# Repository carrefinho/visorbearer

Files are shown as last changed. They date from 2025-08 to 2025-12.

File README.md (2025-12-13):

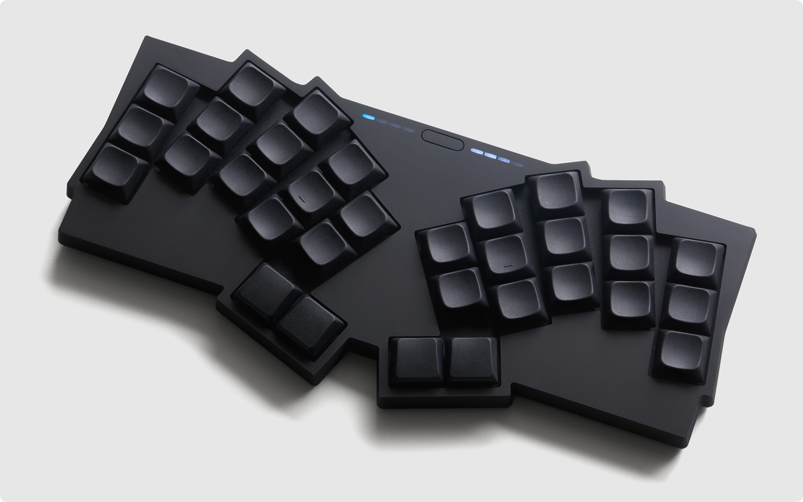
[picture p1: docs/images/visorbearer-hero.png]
Visorbearer keyboard


# Visorbearer

Visorbearer is a 32-key unibody split wireless keyboard featuring 8 RGB LED indicators.

Named after [hummingbirds in the genus Augastes](https://en.wikipedia.org/wiki/Visorbearer) for the Hummingbird layout connection and distinctive white bands on their chests that resemble the LED indicators.

> [!WARNING]
> This is a work in progress.

## To-Do

- [ ] Build Guide & BOM
- [ ] Case Printing Guide
- [ ] Alternative layout case files and guide
- [x] Revision 2 PCB testing + power profiling
- [x] Firmware Notes
- [ ] Design write-up
- [ ] More photos

## Design

https://github.com/user-attachments/assets/812049e3-29ce-48d4-8fe3-20bf21285e64

- 2x 4-segment RGB LED indicators
   - Discreet dead-front design: completely invisible when off
   - Connection bar: Bluetooth profiles and modifier keys
   - Battery bar: percentage and charging status
   - Powered by two TI LP5012 drivers with automatic low-power mode
- 32-key Hummingbird-ish layout with splay and inverted thumb cluster
   - Down to 26-key with case and plate variants
      - 2U thumb key support
- Hot-swap Kailh Choc v1 switches in Choc (18x17mm) spacing
   - <details> <summary>Limited Choc v2 compatibility</summary>

      The PCB is incompatible with older Choc v2 switches that have a third stabilizing pin. Newer Choc v2 releases without this pin work fine, such as: Lofree POM Phantom/Ghost/Specter/Hades and Kailh Hide Mountain/White Rain/Deep Sea Mini Islet/Deep Sea Mini Whale.

      Note that, for Choc v2, there are very few off-the-shelf options for choc-spaced keycaps with MX stems: as of late 2025, the only two are [Taihao THCS](https://shop.tai-hao.com/categories/thcs-low-profile-keycaps) and [Asymplex MX-stem Chicago Steno](https://www.asymplex.xyz/product/made-to-order-mx-stem-cs-kits). You could also 3D-print your own keycaps.

   </details>
- Seeed Studio XIAO nRF52840 **Plus** controller on ZMK firmware
- 3D-printed case and switch plate with switch puller grooves
   - Easily accessible reset button

<picture>
  <source media="(prefers-color-scheme: dark)" srcset="./docs/images/visorbearer-dimensions-dark.png">
  <source media="(prefers-color-scheme: light)" srcset="./docs/images/visorbearer-dimensions-light.png">
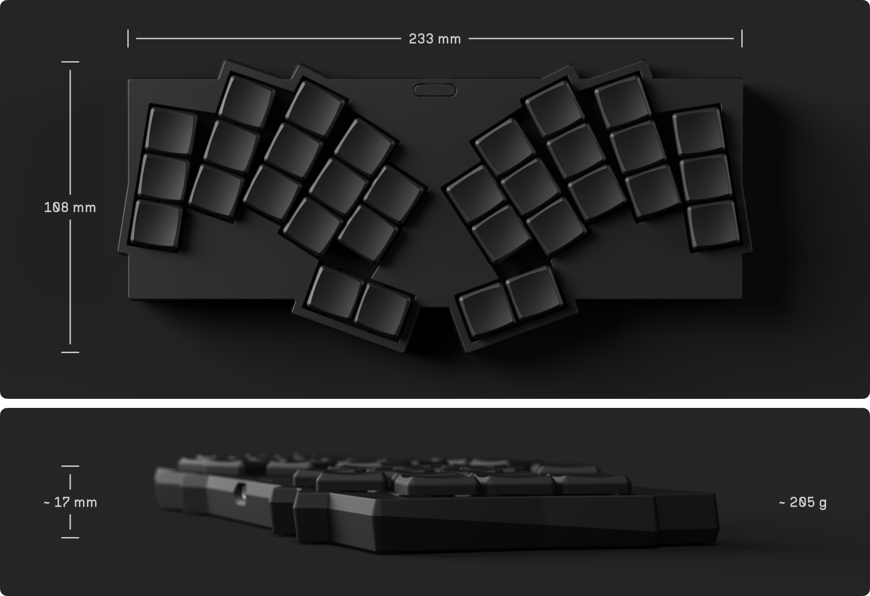
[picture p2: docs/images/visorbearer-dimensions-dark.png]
Visorbearer keyboard dimensions
  
</picture>

## Build Guide

> [!NOTE]
> Revision 2 PCB is tested and working. Build guide is work in progress.

[View the PCB on KiCanvas.](https://kicanvas.org/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)

[Find the build guide here.](/docs/build-guide.md)

## Firmware

[Find the ZMK module here.](https://github.com/carrefinho/visorbearer-zmk-module)

## Gallery

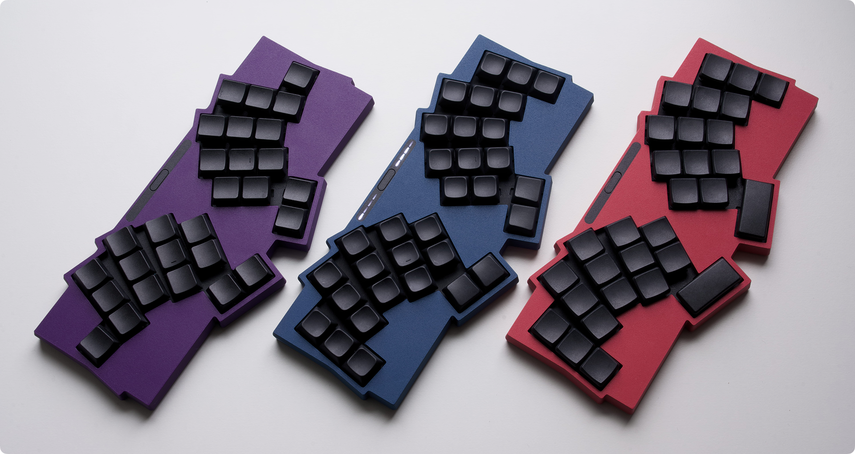
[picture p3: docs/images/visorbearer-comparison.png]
Comparison of Visorbearer keyboard in single pinkie, standard 32-key, and 2x 2U thumb layouts


## Inspirations & Acknowledgments

- Aesthetics
   - [GEIGEIGEIST/TOTEM](https://github.com/GEIGEIGEIST/TOTEM)
   - [weteor/Grumpy](https://github.com/weteor/Grumpy)
   - [dohn-joh/alias](https://github.com/dohn-joh/alias)
- Layout
   - [bennytrouser/NostrumX](https://github.com/bennytrouser/NostrumX)
   - [davidphilipbarr/hypergolic](https://github.com/davidphilipbarr/hypergolic)
   - [davidphilipbarr/paroxysm](https://github.com/davidphilipbarr/paroxysm)
   - [grassfedreeve/akohekohe](https://github.com/grassfedreeve/akohekohe)
   - [hazels-garage/bad-wings](https://github.com/hazels-garage/bad-wings/tree/master/v2)
   - [kilipan/zilpzalp](https://github.com/kilipan/zilpzalp)
   - [weteor/Fitis](https://github.com/weteor/Fitis)
   - [weteor/Tipper-TF](https://github.com/weteor/Tipper-TF)
- LED indicator
   - [GEIGEIGEIST/KLOTZ](https://github.com/GEIGEIGEIST/KLOTZ)
   - [caksoylar/zmk-rgbled-widget](https://github.com/caksoylar/zmk-rgbled-widget): LED code
- Case
   - [duckyb/urchin](https://github.com/duckyb/urchin): Snap fit design
- And the lovely folks on the Fingerpunch discord who were along for the ride!

## License

Visorbearer is licensed under CERN-OHL-P-2.0.

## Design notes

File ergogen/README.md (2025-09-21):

Ergogen was only used to generate key positions, rest of the design including PCB outline and component placement was done with pcb_ref.dxf in Fusion and KiCad.

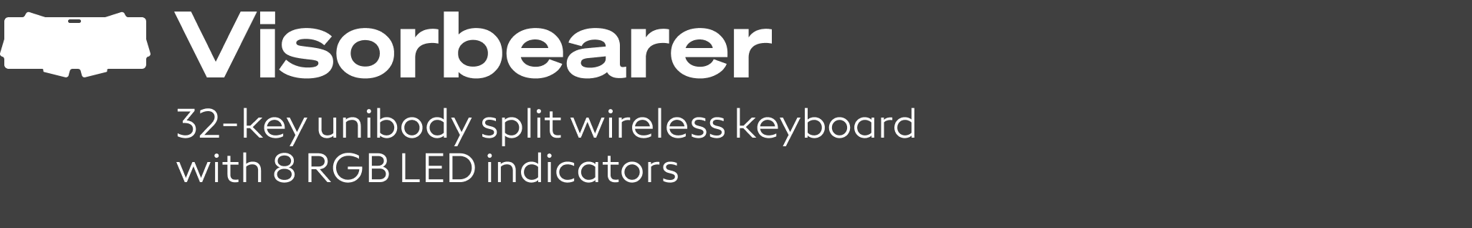
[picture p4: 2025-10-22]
docs/images/visorbearer-heading-dark.png

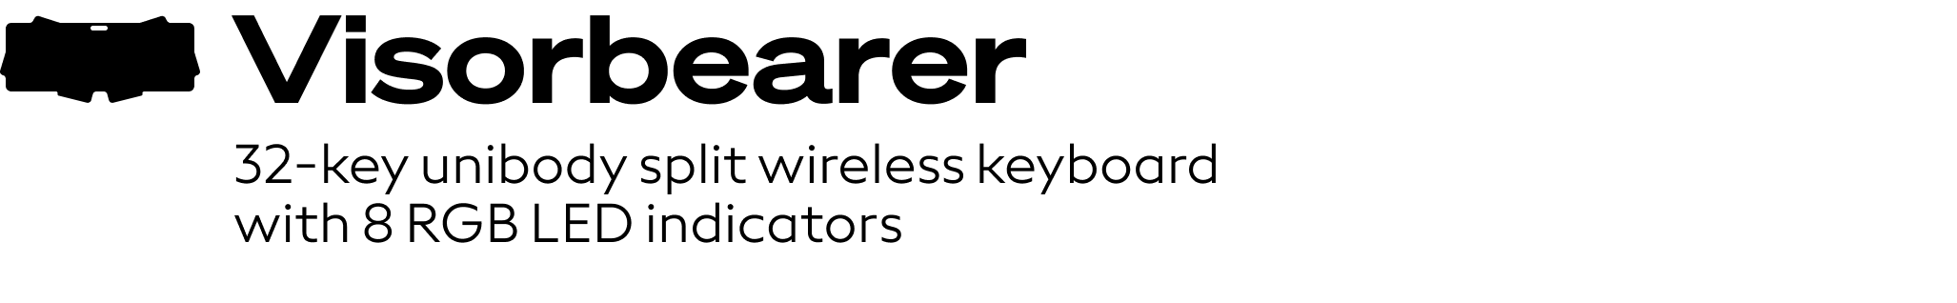
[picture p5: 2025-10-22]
docs/images/visorbearer-heading-light.png

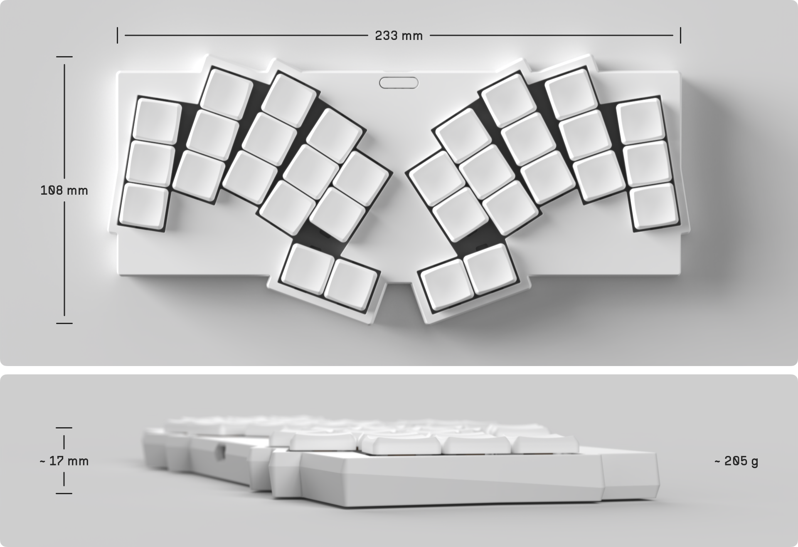
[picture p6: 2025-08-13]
docs/images/visorbearer-dimensions-light.png

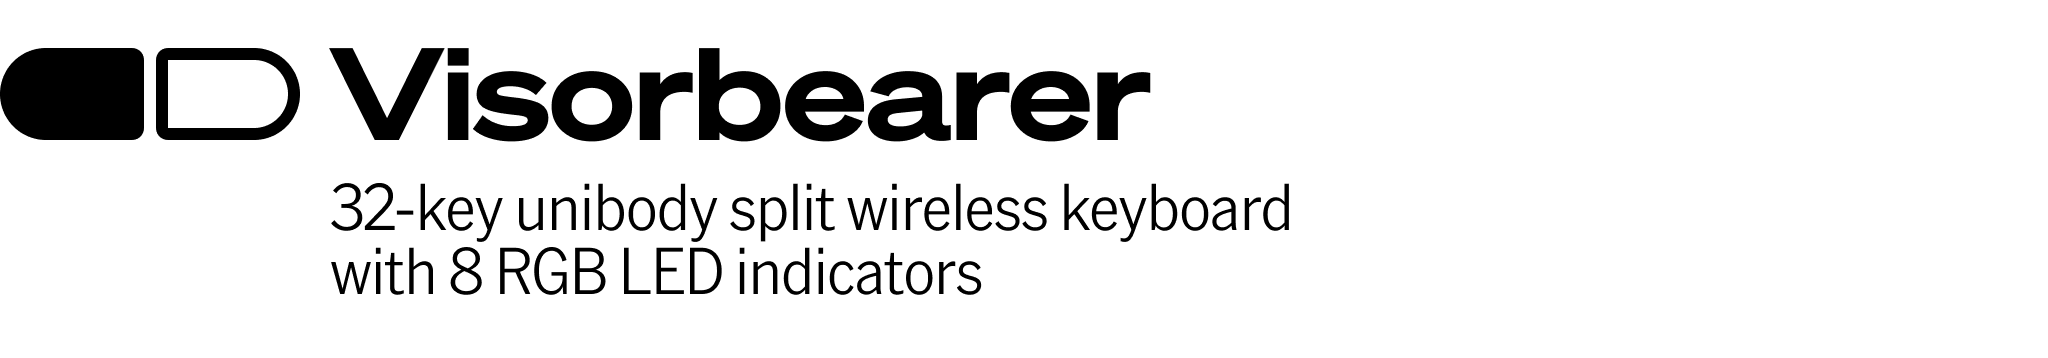
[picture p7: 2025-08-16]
docs/images/visorbearer-heading-dark-1.png

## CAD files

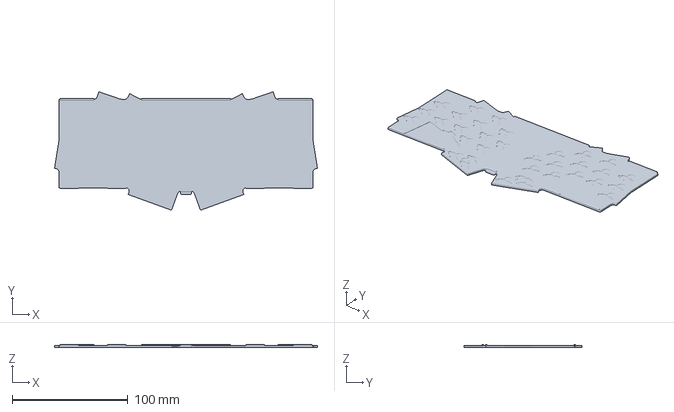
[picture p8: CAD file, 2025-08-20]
case/bottom-cover/visorbearer_bottom_cover_standard.3mf
227.2 x 102.4 x 3.00 mm

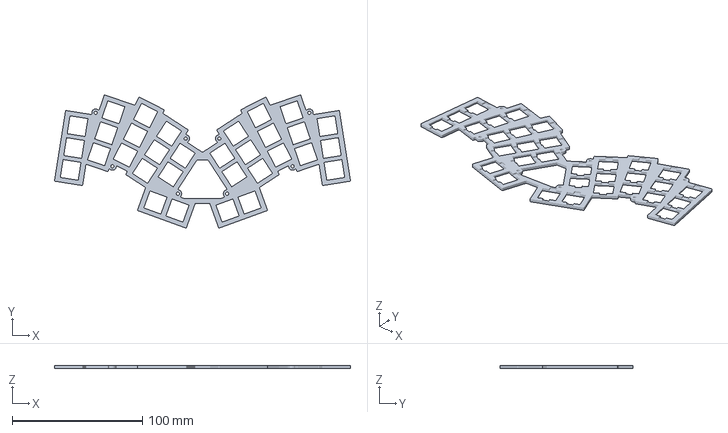
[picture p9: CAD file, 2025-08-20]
case/switch-plate/visorbearer_plate_standard.3mf
227.1 x 102.1 x 2.20 mm

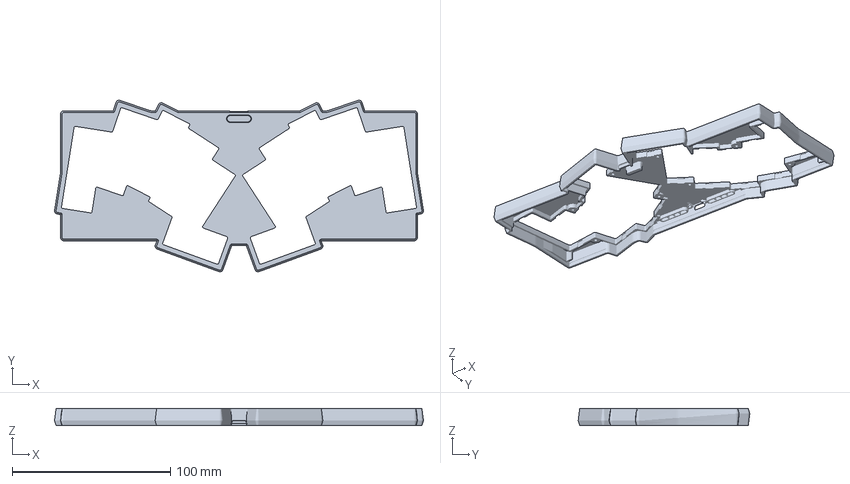
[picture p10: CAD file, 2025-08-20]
case/top-case/visorbearer_top_case_standard.3mf
233.0 x 108.4 x 11.0 mm

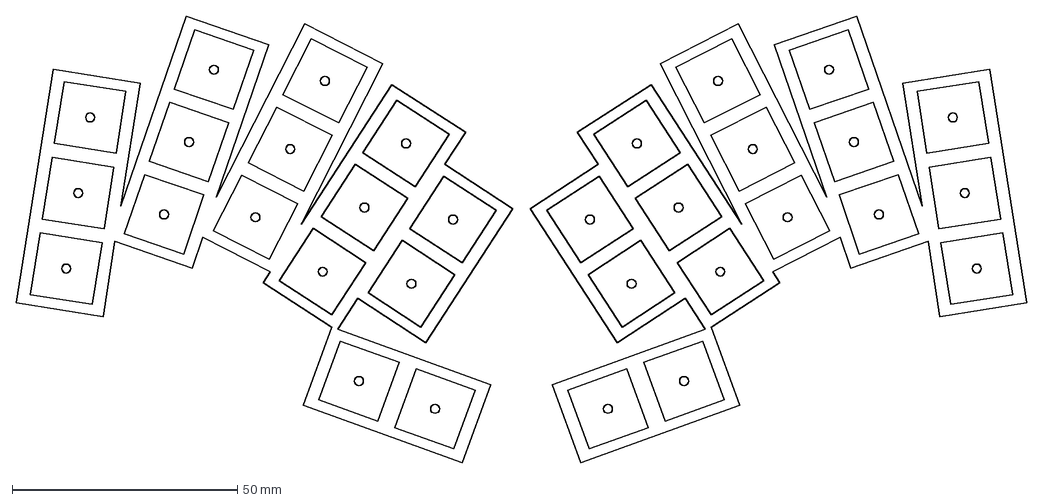
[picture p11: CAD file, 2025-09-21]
ergogen/pcb_ref.dxf
224.5 x 99.3 mm

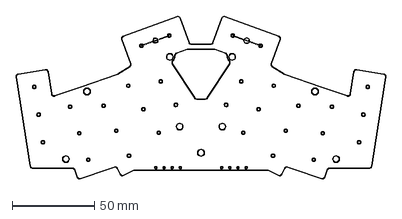
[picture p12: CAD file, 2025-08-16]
visorbearer-pcb/049b-32-pcb-ref.dxf
224.3 x 98.7 mm

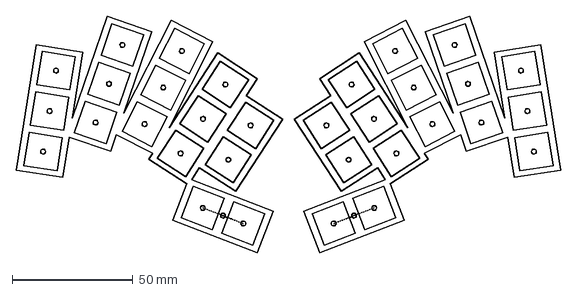
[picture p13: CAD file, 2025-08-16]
visorbearer-pcb/pcb_ref.dxf
225.5 x 98.0 mm

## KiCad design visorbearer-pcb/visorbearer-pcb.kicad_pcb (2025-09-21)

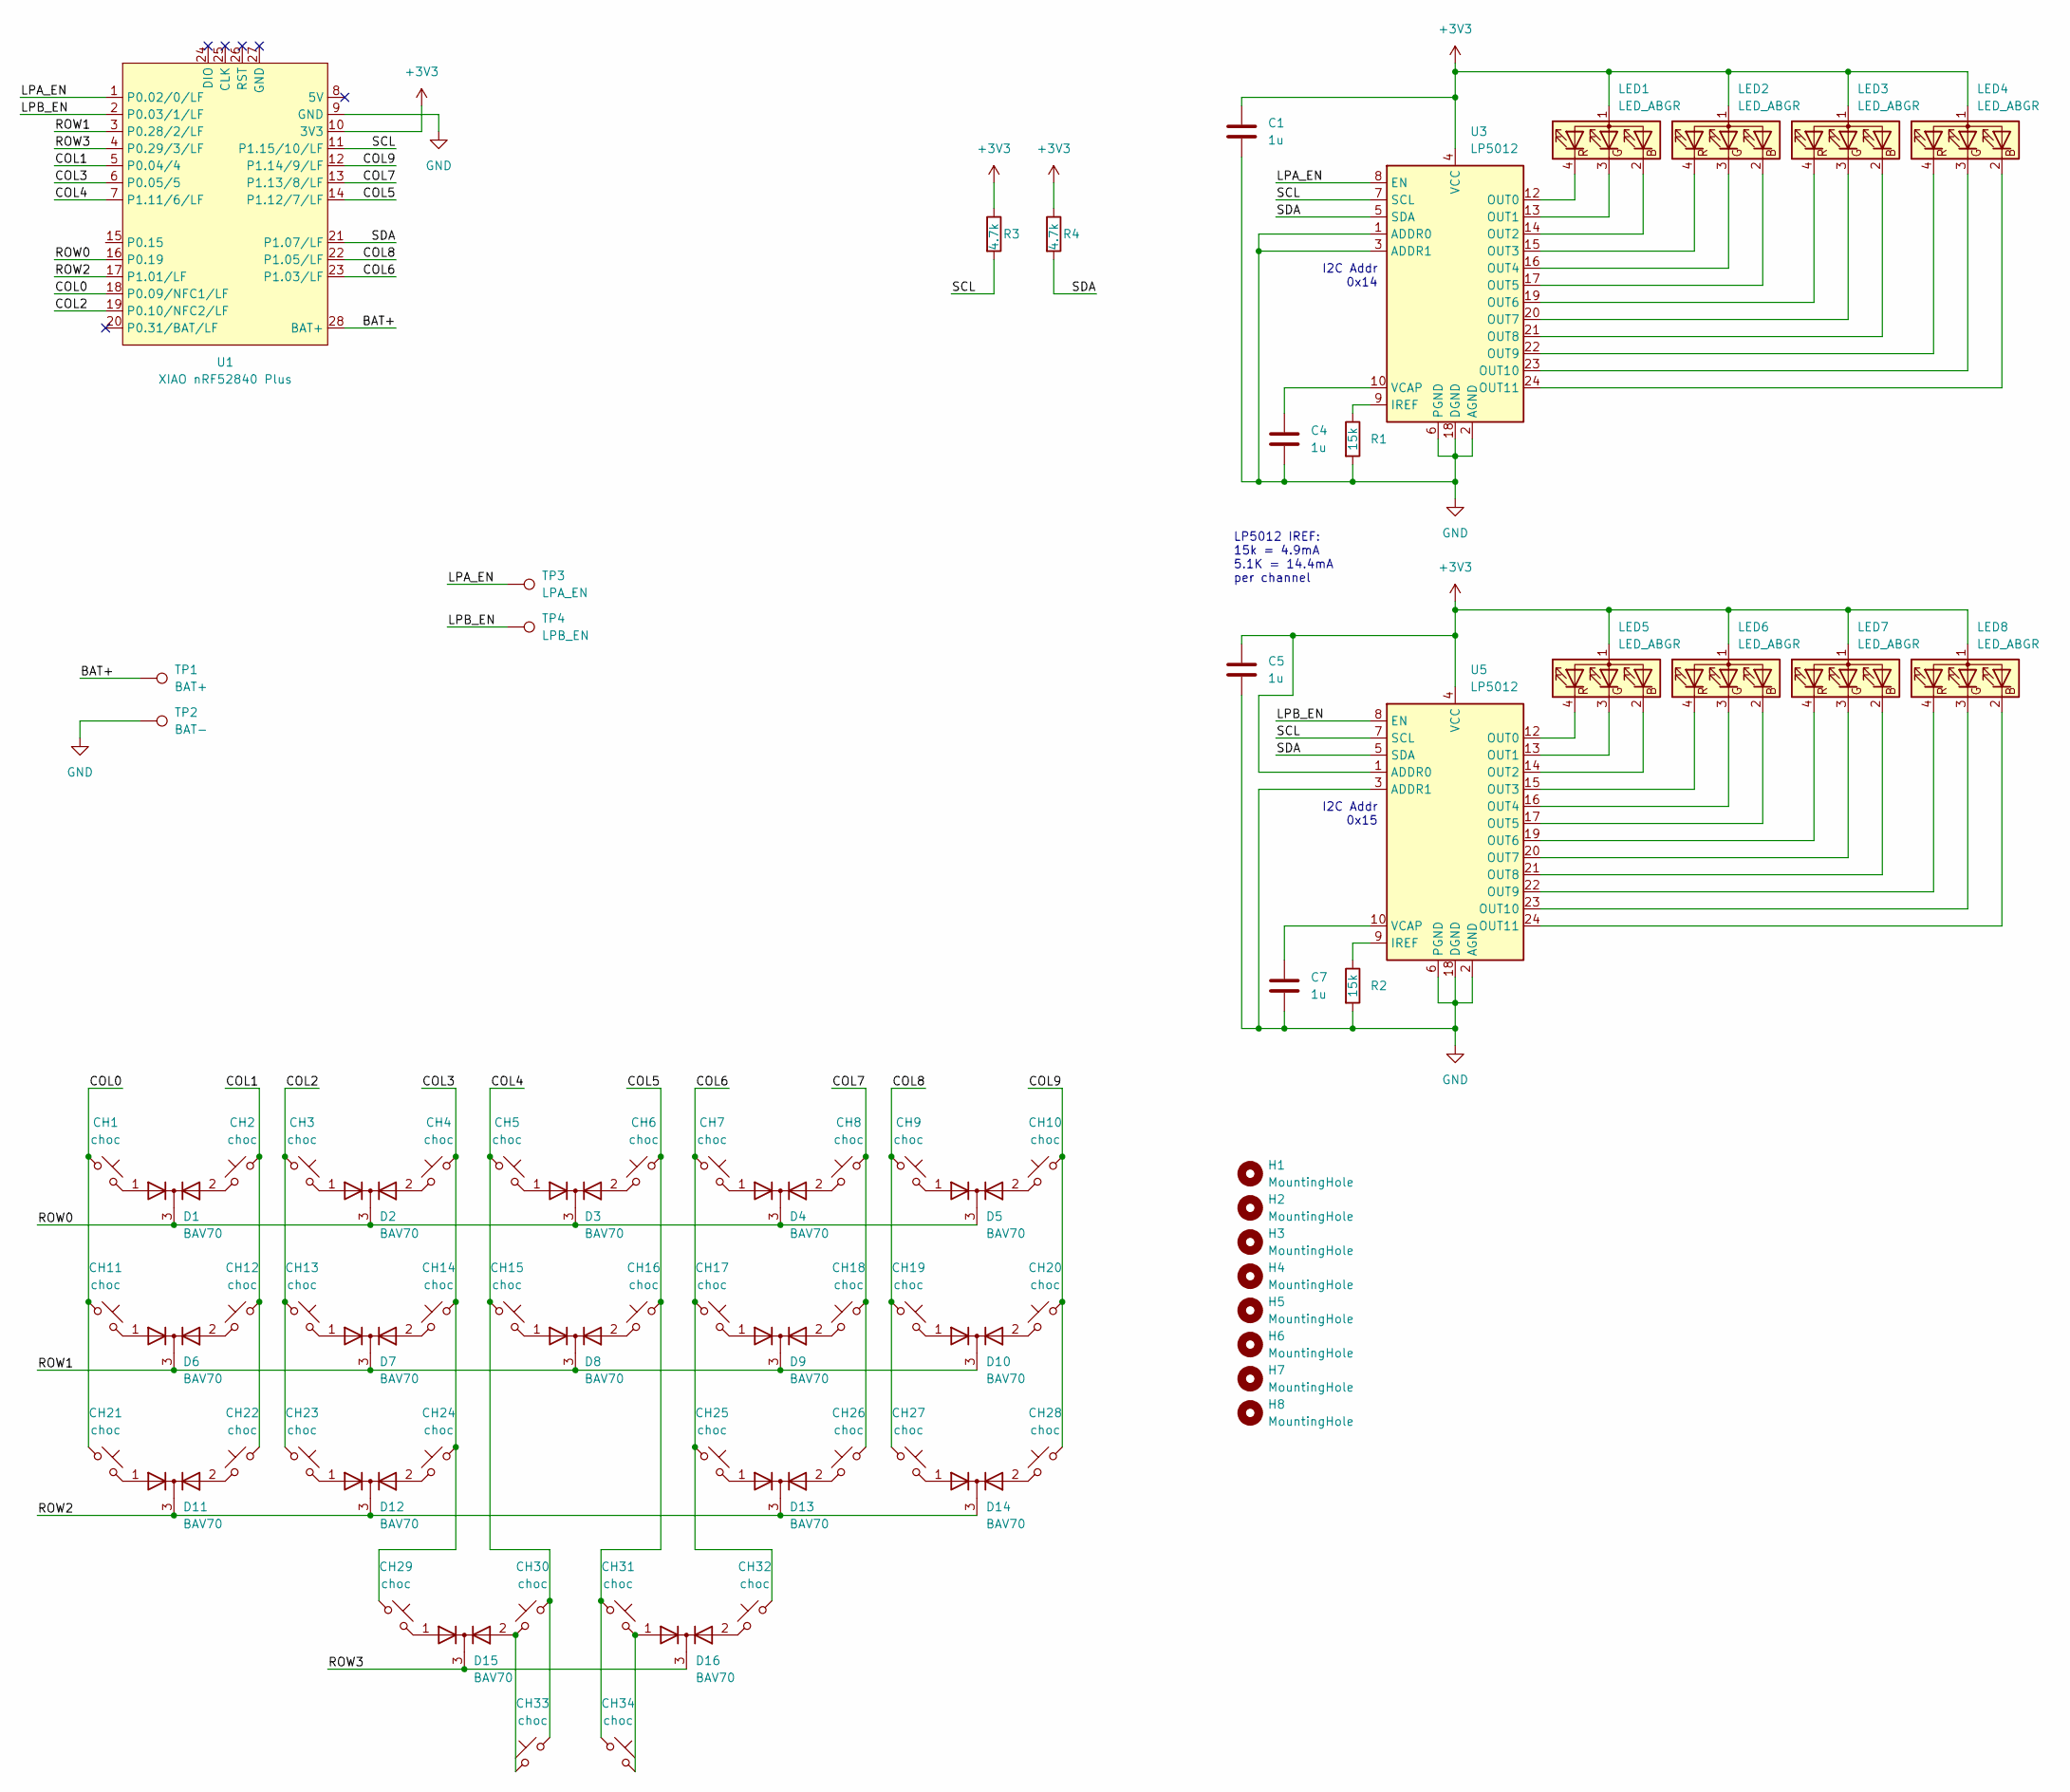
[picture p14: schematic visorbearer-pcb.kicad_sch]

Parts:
C1, C4, C5, C7: 1u; C_0603_1608Metric
CH1, CH2, CH3, CH4, CH5, CH6, CH7, CH8, CH9, CH10, CH11, CH12, CH13, CH14, CH15, CH16, CH17, CH18, CH19, CH20, CH21, CH22, CH23, CH24, CH25, CH26, CH27, CH28, CH29, CH30, CH31, CH32, CH33, CH34: choc; SW_choc_v1v2_noStab_HS_MBK_1u
D1, D2, D3, D4, D5, D6, D7, D8, D9, D10, D11, D12, D13, D14, D15, D16: BAV70; SOT-23_Handsoldering
H1, H2, H3, H4, H5, H6, H7, H8: MountingHole; MountingHole_2.2mm_M2_ISO7380_Pad_TopBottom_BackSilkRing
LED1, LED2, LED3, LED4, LED5, LED6, LED7, LED8: LED_ABGR; LED_Cree-PLCC4_2x2mm_CW
R1, R2: 15k; R_0603_1608Metric
R3, R4: 4.7k; R_0603_1608Metric
TP1: BAT+; TestPoint_Pad_3.0x3.0mm
TP2: BAT-; TestPoint_Pad_3.0x3.0mm
TP3: LPA_EN; TestPoint_Pad_D1.5mm
TP4: LPB_EN; TestPoint_Pad_D1.5mm
U1: XIAO nRF52840 Plus; Xiao_nRF52840_Plus
U3, U5: LP5012; TSSOP-24_4.4x7.8mm_P0.65mm

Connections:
+3V3: C1.1, C5.1, LED1.1 (A), LED2.1 (A), LED3.1 (A), LED4.1 (A), LED5.1 (A), LED6.1 (A), LED7.1 (A), LED8.1 (A), R3.1, R4.1, U1.10 (3V3), U3.4 (VCC), U5.1 (ADDR0), U5.4 (VCC)
/BAT+: TP1.1, U1.28 (BAT+)
/COL0: CH1.1, CH11.1, CH21.1, U1.18 (P0.09/NFC1/LF)
/COL1: CH2.1, CH12.1, CH22.1, U1.5 (P0.04/4)
/COL2: CH3.1, CH13.1, CH23.1, U1.19 (P0.10/NFC2/LF)
/COL3: CH4.1, CH14.1, CH24.1, CH29.1, U1.6 (P0.05/5)
/COL4: CH5.1, CH15.1, CH30.1, CH33.1, U1.7 (P1.11/6/LF)
/COL5: CH6.1, CH16.1, CH31.1, CH34.1, U1.14 (P1.12/7/LF)
/COL6: CH7.1, CH17.1, CH25.1, CH32.1, U1.23 (P1.03/LF)
/COL7: CH8.1, CH18.1, CH26.1, U1.13 (P1.13/8/LF)
/COL8: CH9.1, CH19.1, CH27.1, U1.22 (P1.05/LF)
/COL9: CH10.1, CH20.1, CH28.1, U1.12 (P1.14/9/LF)
/LPA_EN: TP3.1, U1.1 (P0.02/0/LF), U3.8 (EN)
/LPB_EN: TP4.1, U1.2 (P0.03/1/LF), U5.8 (EN)
/ROW0: D1.3 (K), D2.3 (K), D3.3 (K), D4.3 (K), D5.3 (K), U1.16 (P0.19)
/ROW1: D6.3 (K), D7.3 (K), D8.3 (K), D9.3 (K), D10.3 (K), U1.3 (P0.28/2/LF)
/ROW2: D11.3 (K), D12.3 (K), D13.3 (K), D14.3 (K), U1.17 (P1.01/LF)
/ROW3: D15.3 (K), D16.3 (K), U1.4 (P0.29/3/LF)
/SCL: R3.2, U1.11 (P1.15/10/LF), U3.7 (SCL), U5.7 (SCL)
/SDA: R4.2, U1.21 (P1.07/LF), U3.5 (SDA), U5.5 (SDA)
GND: C1.2, C4.2, C5.2, C7.2, R1.2, R2.2, TP2.1, U1.9 (GND), U3.1 (ADDR0), U3.2 (AGND), U3.3 (ADDR1), U3.6 (PGND), U3.18 (DGND), U5.2 (AGND), U5.3 (ADDR1), U5.6 (PGND), U5.18 (DGND)
unnamed: CH1.2, D1.1 (A)
unnamed: CH2.2, D1.2 (A)
unnamed: CH3.2, D2.1 (A)
unnamed: CH4.2, D2.2 (A)
unnamed: CH5.2, D3.1 (A)
unnamed: CH6.2, D3.2 (A)
unnamed: CH7.2, D4.1 (A)
unnamed: CH8.2, D4.2 (A)
unnamed: CH9.2, D5.1 (A)
unnamed: CH10.2, D5.2 (A)
unnamed: CH11.2, D6.1 (A)
unnamed: CH12.2, D6.2 (A)
unnamed: CH13.2, D7.1 (A)
unnamed: CH14.2, D7.2 (A)
unnamed: CH15.2, D8.1 (A)
unnamed: CH16.2, D8.2 (A)
unnamed: CH17.2, D9.1 (A)
unnamed: CH18.2, D9.2 (A)
unnamed: CH19.2, D10.1 (A)
unnamed: CH20.2, D10.2 (A)
unnamed: CH21.2, D11.1 (A)
unnamed: CH22.2, D11.2 (A)
unnamed: CH23.2, D12.1 (A)
unnamed: CH24.2, D12.2 (A)
unnamed: CH25.2, D13.1 (A)
unnamed: CH26.2, D13.2 (A)
unnamed: CH27.2, D14.1 (A)
unnamed: CH28.2, D14.2 (A)
unnamed: CH29.2, D15.1 (A)
unnamed: CH30.2, CH33.2, D15.2 (A)
unnamed: CH31.2, CH34.2, D16.1 (A)
unnamed: CH32.2, D16.2 (A)
unnamed: LED1.2 (BK), U3.14 (OUT2)
unnamed: LED1.3 (GK), U3.13 (OUT1)
unnamed: LED1.4 (RK), U3.12 (OUT0)
unnamed: LED2.2 (BK), U3.17 (OUT5)
unnamed: LED2.3 (GK), U3.16 (OUT4)
unnamed: LED2.4 (RK), U3.15 (OUT3)
unnamed: LED3.2 (BK), U3.21 (OUT8)
unnamed: LED3.3 (GK), U3.20 (OUT7)
unnamed: LED3.4 (RK), U3.19 (OUT6)
unnamed: LED4.2 (BK), U3.24 (OUT11)
unnamed: LED4.3 (GK), U3.23 (OUT10)
unnamed: LED4.4 (RK), U3.22 (OUT9)
unnamed: LED5.2 (BK), U5.14 (OUT2)
unnamed: LED5.3 (GK), U5.13 (OUT1)
unnamed: LED5.4 (RK), U5.12 (OUT0)
unnamed: LED6.2 (BK), U5.17 (OUT5)
unnamed: LED6.3 (GK), U5.16 (OUT4)
unnamed: LED6.4 (RK), U5.15 (OUT3)
unnamed: LED7.2 (BK), U5.21 (OUT8)
unnamed: LED7.3 (GK), U5.20 (OUT7)
unnamed: LED7.4 (RK), U5.19 (OUT6)
unnamed: LED8.2 (BK), U5.24 (OUT11)
unnamed: LED8.3 (GK), U5.23 (OUT10)
unnamed: LED8.4 (RK), U5.22 (OUT9)
unnamed: R1.1, U3.9 (IREF)
unnamed: C4.1, U3.10 (VCAP)
unnamed: R2.1, U5.9 (IREF)
unnamed: C7.1, U5.10 (VCAP)

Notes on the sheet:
LP5012 IREF: 15k = 4.9mA 5.1K = 14.4mA per channel
I2C Addr 0x14
I2C Addr 0x15

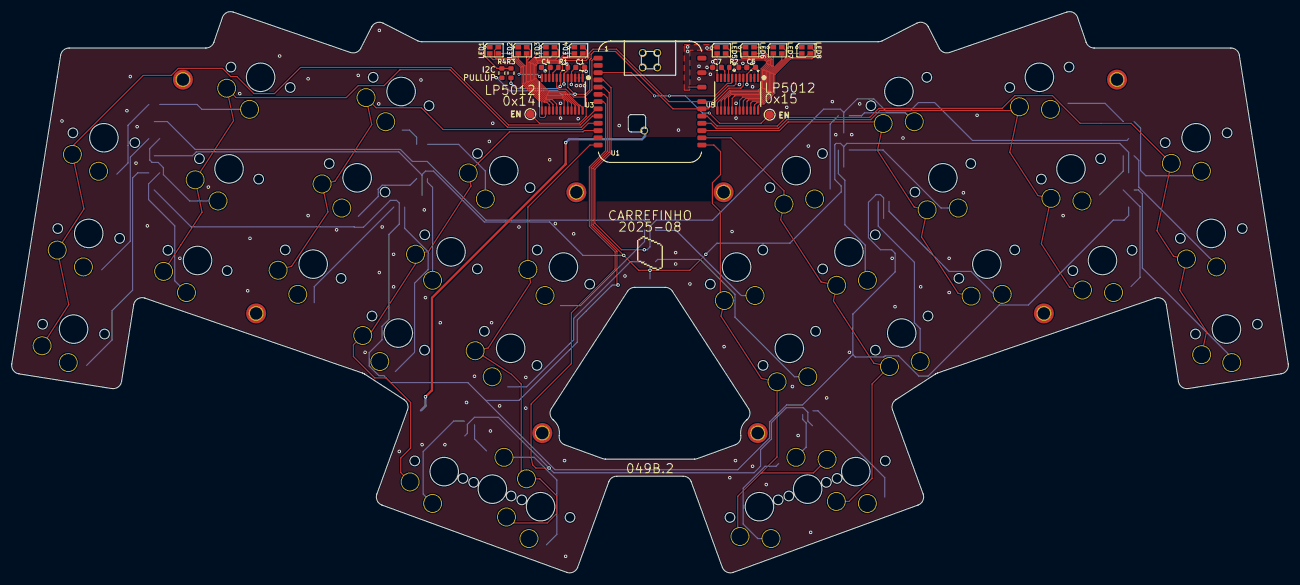
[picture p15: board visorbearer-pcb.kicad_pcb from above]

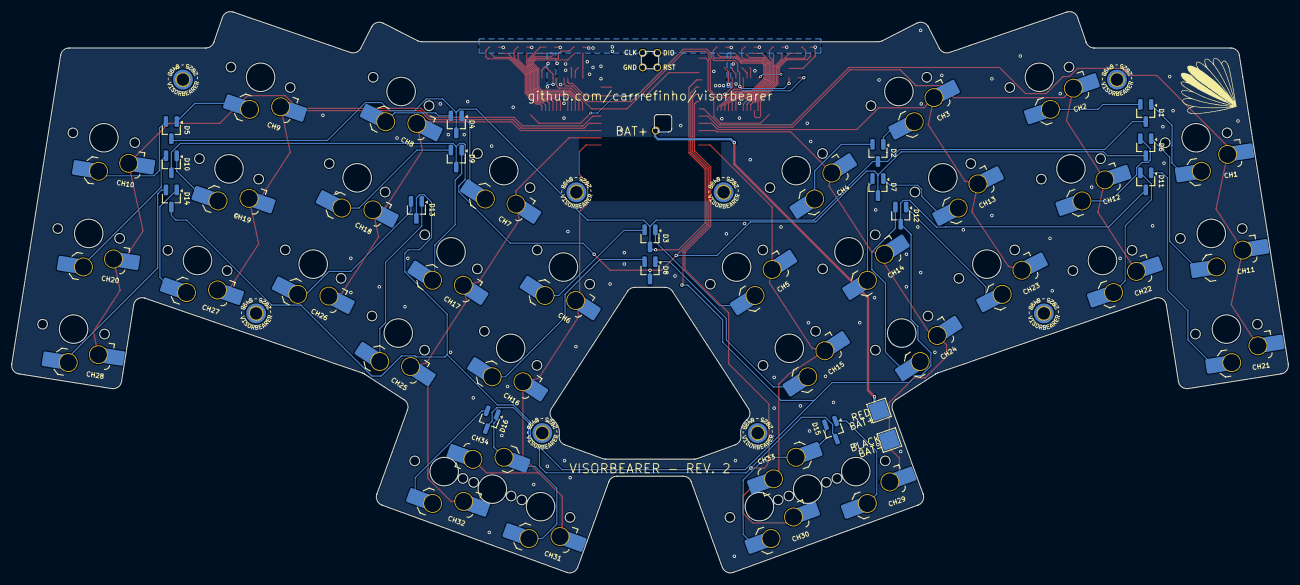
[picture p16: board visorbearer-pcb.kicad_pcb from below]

Board: 2 copper layers, 224.0 x 98.5 mm, 81 parts (52 on the bottom side), 81 nets.

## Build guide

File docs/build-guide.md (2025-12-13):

- [PCB Assembly Guide](./pcb-assembly.md)
- [Case Printing Guide](./case-printing.md)

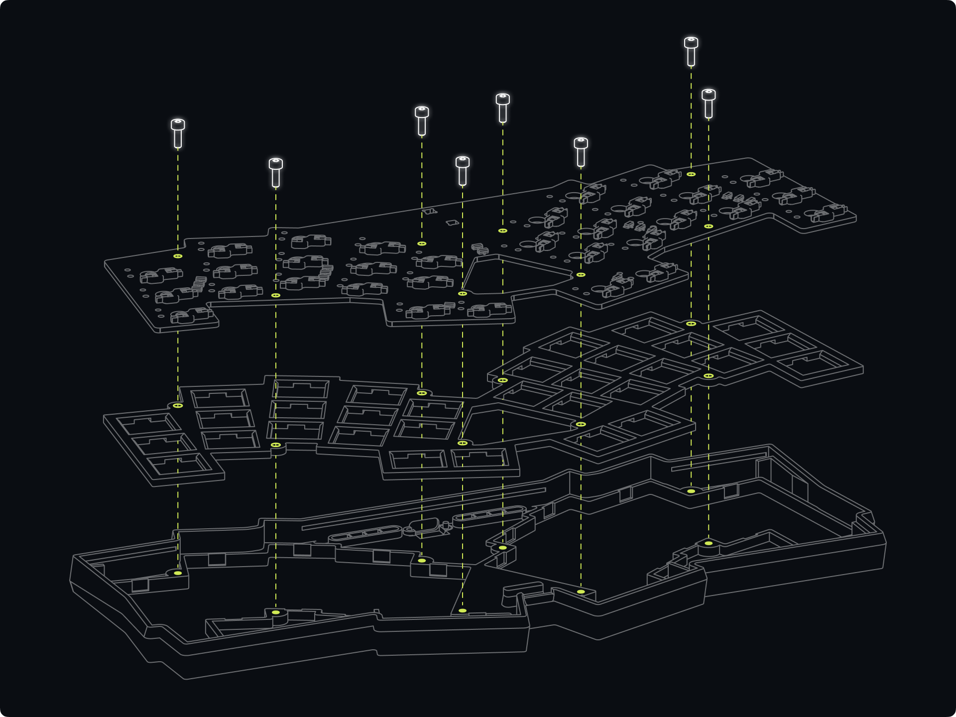
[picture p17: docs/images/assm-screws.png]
Install 8x M2x6 Screws

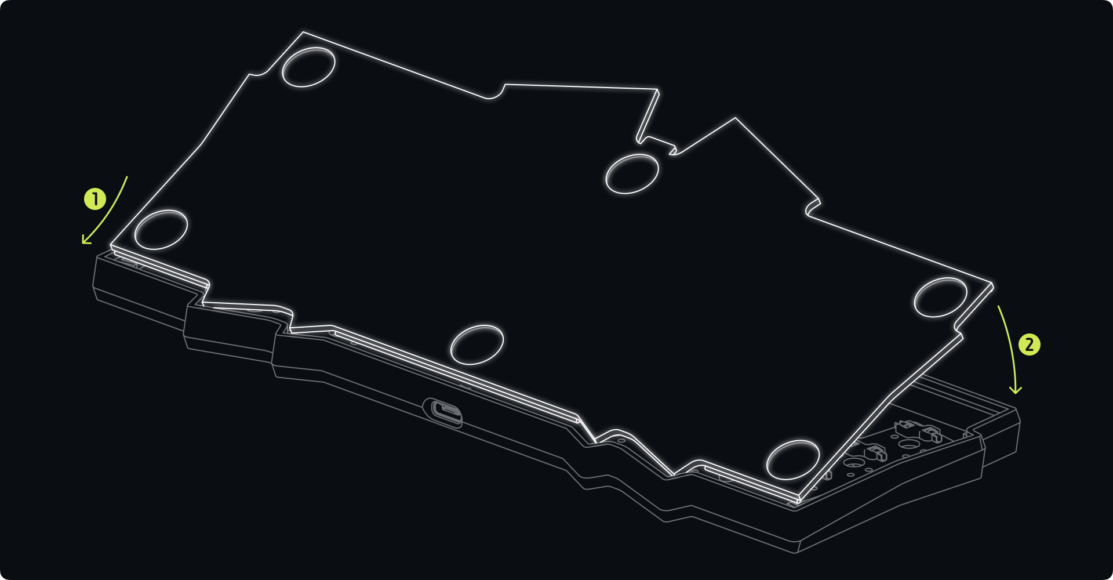
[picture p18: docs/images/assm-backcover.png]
Install Back Cover


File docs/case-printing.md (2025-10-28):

# Case Printing Guide

## Top Case

### First Layer & LED Bezel

A good first layer is crucial since it is the exposed top surface of the board. At 0.08-0.12mm thickness, it enables the dead-front effect of the LEDs.

#### Build Plate

Finish will largely depend on the type of build plate. I've tested a few with varying results:

| Type | Finish | Notes |
| --- | --- | --- |
| YOOPAI Doubled Sided Epoxy | Finely textured finish. Adhesion is not the best; corners might curl up slightly. | -0.04 Z offset |
| BIQU CryoGrip Glacier | Slightly shinier and coarser texture than YOOPAI. Very sticky; **best choice overall**. | -0.025 Z offset |
| Bambu Lab Smooth PEI | Very smooth and matte finish when it works. Some filaments show stress marks after removal. | -0.03 Z offset |
| Bambu Lab Cold Plate Supertack | Haven't been able to get a consistent finish with this. |  |
| Bambu Lab Textured PEI | Very pronounced texture; might have pinholes at 0.08mm layer height. Not recommended. | -0.04 Z offset (default)|

Z offset is increased from default values; the extra squish makes infill lines virtually invisible. Speed doesn't matter much, so feel free to crank it up if you're using CryoGrip.

#### Filament Choice

Only neutral shades (black and grey) will display LED colors cleanly without tinting. Lighter colors may show light bleed around case edges. Even among black and grey filaments, light transmission varies significantly and will require some experimentation. Here are a few I've tested:

| Filament | Notes | On Smooth PEI |
| --- | --- | --- |
| Protopasta cMatte PLA Black | About the right amount of translucency at 0.08mm. Extremely matte side wall finish. | Works really well. See photos in the main README. |
| Overture Matte PLA Black | Very opaque; still quite dim at 0.06mm. |  |
| Sunlu PLA Matte Black | Almost 100% opaque, doesn’t work at all. |  |
| Elegoo/Deeplee Matte PLA Black | Lets through quite a bit of light; I use 0.12mm. | Shows stress marks. |
| Bambu Lab PLA Basic Dark Grey | Works well at 0.12mm. |  |
| Bambu Lab PLA Matte Nardo Grey | Works well at 0.1mm. |  |
| Elegoo/Deeplee Matte PLA Grey | Too translucent even at 0.12mm; might work at 0.2mm. The translucency gives it a nice soft-edged look though. |  |

A variant with separate LED bezels is available if you want a colored case body and have a multi-color printer.

> [!NOTE]
> You can tweak the brightness of LEDs by using different valued current limiting resistors. See the [TI LP5012 datasheet](https://www.ti.com/lit/ds/symlink/lp5012.pdf) on how to calculate values. Default is 15kΩ for 4.9mA per channel; higher values result in lower current/dimmer LEDs, and vice versa.

### Print Settings

| Setting | Value | Notes |
| --- | ----- | ----- |
| Layer Height | 0.15mm |  |
| Walls printing order | Inner/Outer/Inner | Helps with outer wall quality. |
| Wall loops | 3 | Required for Inner/Outer/Inner order. |
| Enable support | Y | For USB cutout overhang. |
| Support: Type | tree |  |
| Support: Top Z distance | 0.2mm |  |
| Support: Interface pattern | Concentric |  |
| Support: Top interface spacing | 0mm |  |
|  |  |  |
|  |  |  |

## Switch Plate and Bottom Cover

These parts are less critical in appearance as they are mostly hidden. Standard print settings should work fine.

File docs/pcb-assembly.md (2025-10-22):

# PCB Assembly Guide

> [!WARNING]
> The Visorbearer PCB uses fine-pitch SMD components, so it’s better suited to builders with some surface-mount soldering experience.

> [!TIP]
> My personal approach is to use a mixture of drag soldering for the LED drivers and XIAO, and paste with hot plate for LEDs and passives.

## PCB Bill of Materials

| Qty | Reference(s) | Part number | Notes and links |
| --- | --- | --- | --- |
| 1 | U1 | Seeed Studio XIAO nRF52840 **Plus**  | **Plus** variant only<br>https://www.seeedstudio.com/Seeed-Studio-XIAO-nRF52840-Plus-p-6359.html |
| 2 | U3, U5 | LP5012PWR | TSSOP24 RGB LED driver<br>https://www.mouser.com/ProductDetail/Texas-Instruments/LP5012PWR?qs=T94vaHKWudSL6jLwBy12Hg%3D%3D |
| 8 | LED1–LED8 | CLMVC-FKC-CGJJM569aBB7a343 | PLCC4 RGB LED<br>https://www.mouser.com/ProductDetail/941-CLMVG569ABB7A343<br>any CLMVC-FKC LED will work; CGJJM569aBB7a343 is one specific bin |
| 4 | C1, C4, C5, C7 | CL10A105KB8NNNC | 1 µF 25V X5R 0603 multilayer ceramic capacitor<br>https://www.mouser.com/ProductDetail/Samsung-Electro-Mechanics/CL10A105KA8NNNC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<br>Decoupling caps for LED drivers |
| 2 | R1, R2 | ERA-3AEB153V | 15 kΩ 0603 thin-film resistor<br>https://www.mouser.com/ProductDetail/Panasonic/ERA-3AEB153V?qs=1VWA5LkbEap3wo6XEtDQIA%3D%3D<br>LED current reference resistor for LED drivers |
| 2 | R3, R4 | ERA-3AEB472V | 4.7 kΩ 0603 thin-film resistor<br>https://www.mouser.com/ProductDetail/Panasonic/ERA-3AEB472V?qs=1VWA5LkbEaqNFnF6JmW5eg%3D%3D<br>I²C pull-up resistors |
| 16 | D1–D16 | BAV70 | SOT-23 Dual switching diode<br>https://www.mouser.com/ProductDetail/637-BAV70 |
| 34 | CH1–CH34 | CPG135001S30 | Kailh Choc hot-swap sockets |
| 1 | - | 801735 | 400mAh Lithium polymer battery<br>https://www.adafruit.com/product/3898<br>802030 400mAh and 601230 200mAh are also good options. The common 301230 110mAh works too but you might want a bit of double sided tape to fix the battery to the case. |

[View an interactive version of the BOM here](https://htmlpreview.github.io/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).

## Component Placement

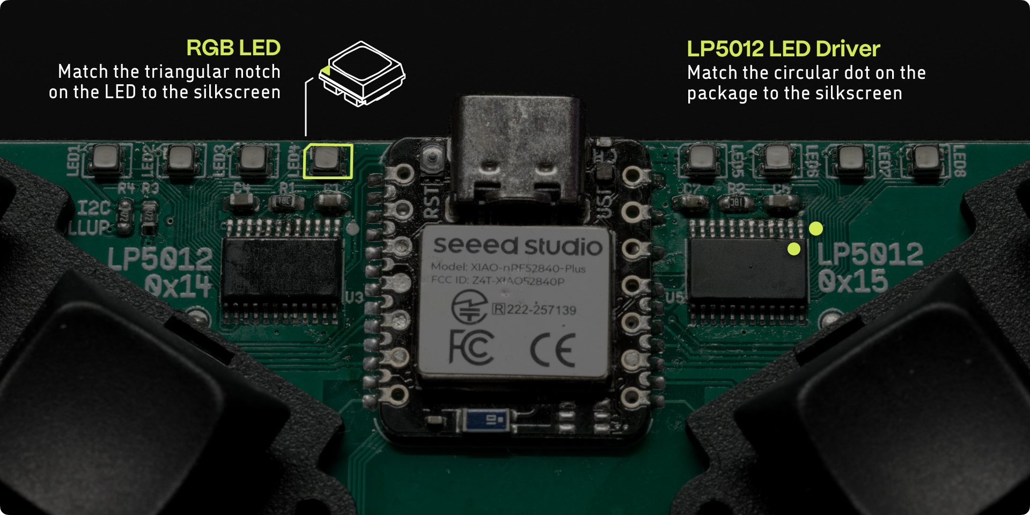
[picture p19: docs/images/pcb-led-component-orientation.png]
LED and LED driver component orientation diagram


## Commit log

2025-08-13 consistent lower case v
2025-08-14 add rev 2 pcb warning
2025-08-16 Add PCB
    [049b-32-pcb-ref.dxf, pcb_ref.dxf, visorbearer-pcb.kicad_pcb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]
2025-08-19 pcb: change to hand-solderable diode footprint, move battery pads, add LP5012 EN test points
    [visorbearer-pcb.kicad_pcb, visorbearer-pcb.kicad_sch]
2025-08-20 add standard case files & update pcb
    [visorbearer-pcb.kicad_pcb, visorbearer_bottom_cover_standard.3mf, visorbearer_plate_standard.3mf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]
2025-09-21 add ergogen files
    [pcb_ref.dxf, visorbearer-pcb.kicad_pcb]
2025-10-12 update readme and work on case printing guide
2025-10-16 update pcb assembly guide
2025-10-16 increase text size of LED component orientation image
2025-10-16 update LED component orientation image
2025-10-20 update case priting guide
2025-10-20 update BOM, fix broken links
2025-12-13 add assembly diagrams
